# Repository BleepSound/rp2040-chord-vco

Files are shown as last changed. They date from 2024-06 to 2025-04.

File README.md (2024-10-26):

# RP2040 VCO (Clone, made by Hagiwo)

VCO clone, originally made by HAGIWO ([link](https://note.com/solder_state/n/n64b91a171218) in japanese)

RP2040 chord VCO clone in SMD.

5-polyphonic Chord VCO module.
There are 8 types of tones.
With a built-in quantizer and automatic harmonics function, if you input a suitable CV, it will play a nice chord progression.

**Switch indications:**

You'll notice numbers along the central 3 position switch. The table below explains each position's function. 

| Position | 1 | 2 | 3 |
|---|:---:|:---:|:---:|
| Function | arpeggio | chord with root | chord without root |

## Schematics

RP2040 VCO schematic

## BoM

[See bom](documentation/bom/RP2040-VCO_V1.2--iBoM.html)

## Build Informations

Full CMS build

:warning: When building this module, do it in this order (from smallest component to highest):

- Start by soldering all the CMS components in the order you want on both sides of the PCB.
- Then do all the through hole components
- To solder the headers, place them and place both PCBs in their final postion before fully soldering the pin headers/sockets.

For the next parts, always place them without soldering them on: 
- jacks, pots and switches that go throught the front panel

Once placed, put the front panel in place, then fasten all components to it. Once this is done, you can solder all the remaining components.

### V1.1
- you HAVE TO rotate SW1 180° for the built in LED to work.
- Issues on front panel (wrong label and missing info)

### V1.2
 - Fix issues on SW1
 - Update front panel look to include all informations

## Images

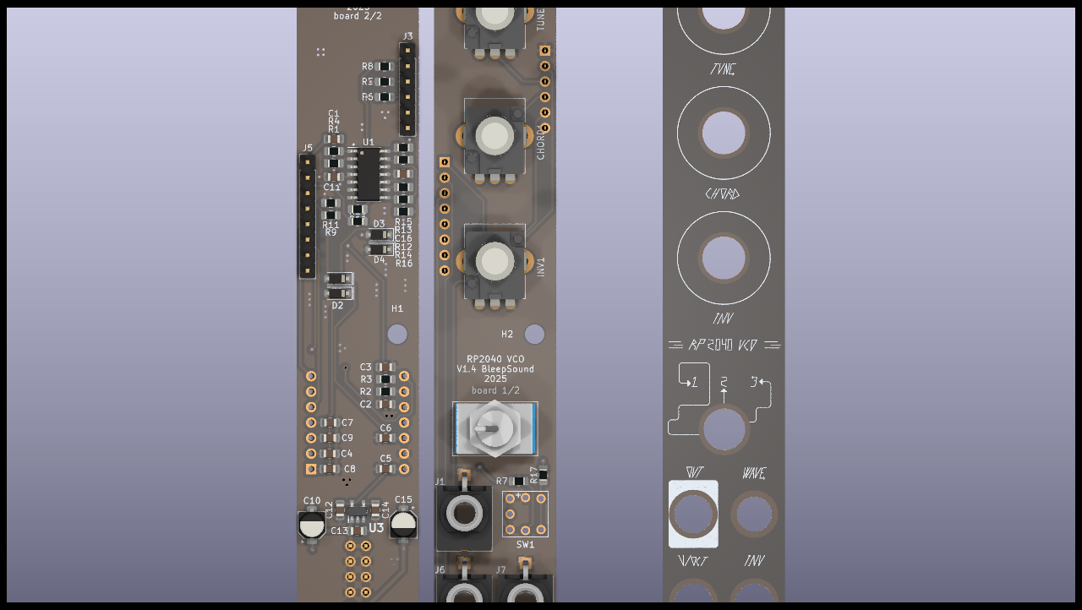
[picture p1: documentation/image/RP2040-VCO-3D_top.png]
3D (front)


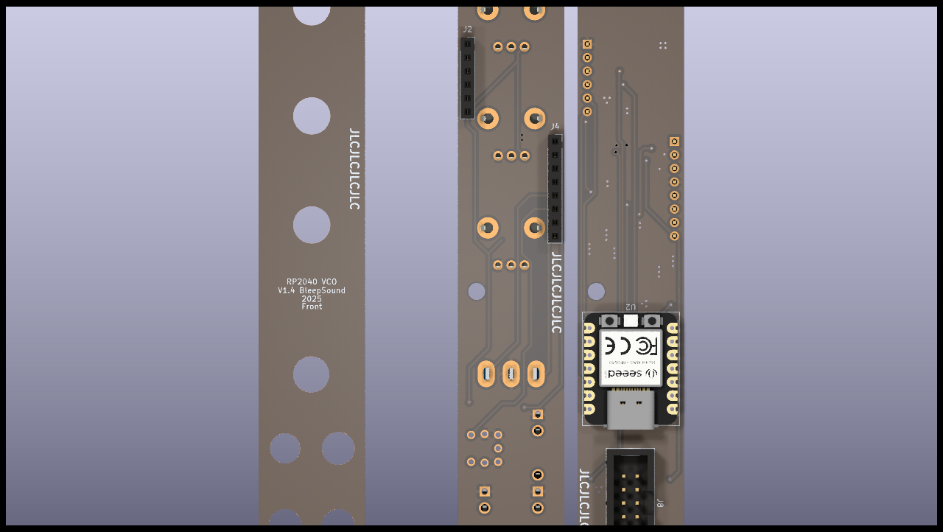
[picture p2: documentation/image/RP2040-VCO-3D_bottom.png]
3D (back)


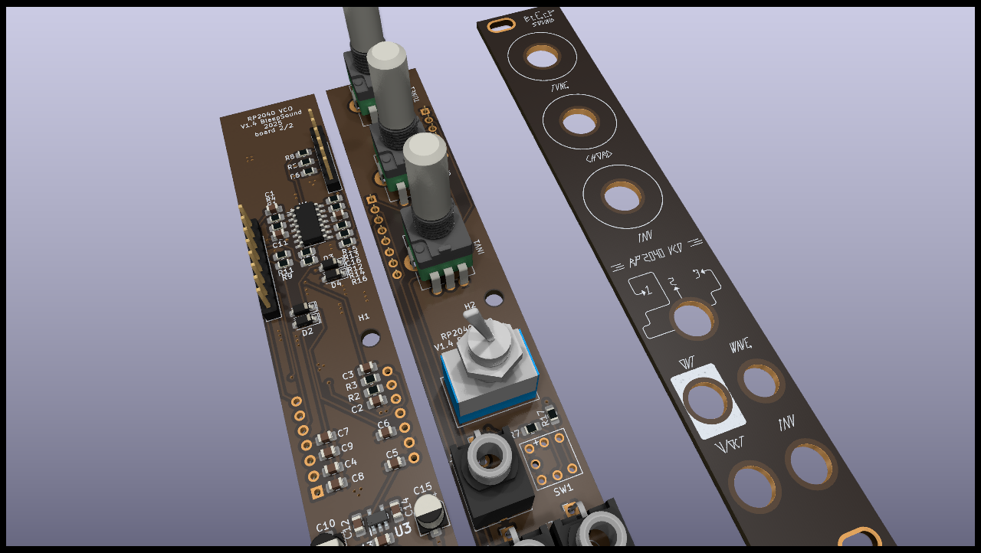
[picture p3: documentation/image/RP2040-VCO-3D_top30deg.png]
3D (iso)


## Software

You'll find the software for that module in the soft folder.

The microcontroler model is: **Seeed XIAO RP2040**

To flash it, use a usb-c cable to connect the RP2040 to your computer and use the arduino IDE (or your preferred IDE) to flash the microcontroler.

If you need any help, you can find a tutorial on how to flash a software via arduino onto a RP2040 [here](https://wiki.seeedstudio.com/XIAO-RP2040-with-Arduino/).

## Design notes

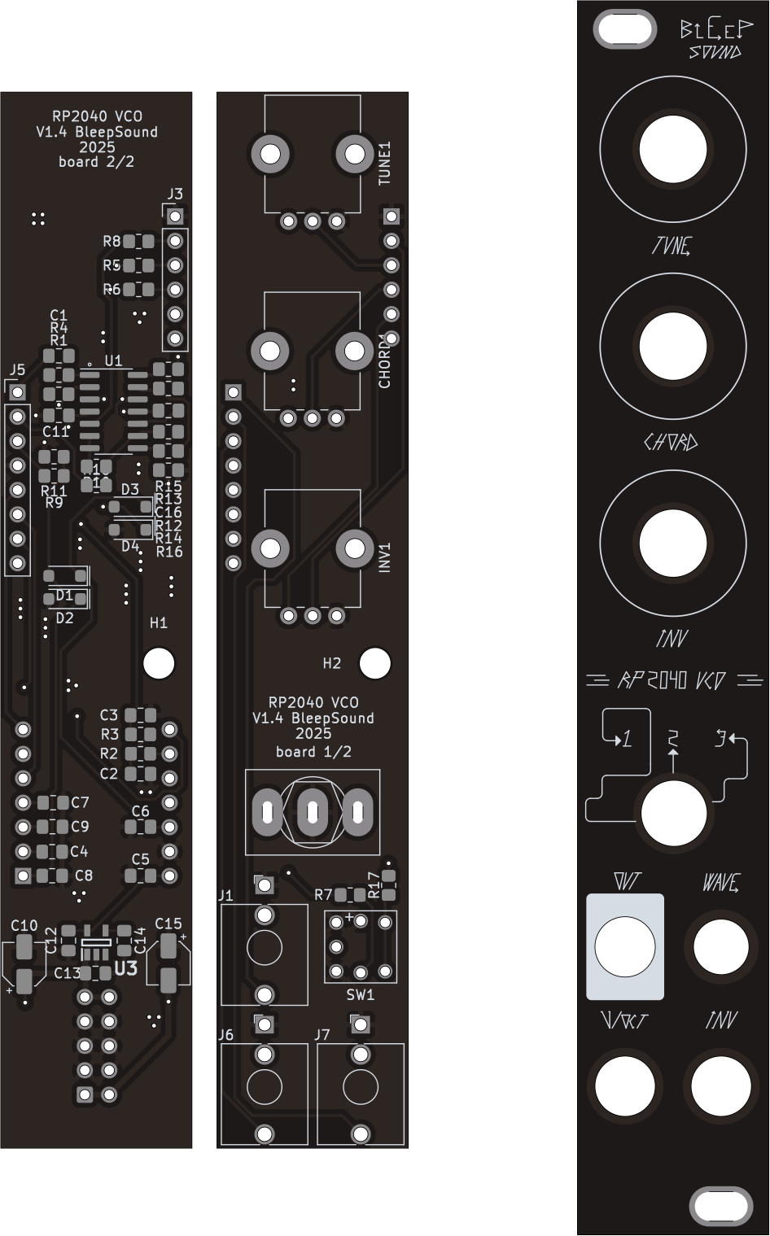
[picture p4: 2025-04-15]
documentation/image/RP2040-VCO-top.png

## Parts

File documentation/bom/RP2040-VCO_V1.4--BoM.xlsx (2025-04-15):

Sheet: BoM
RP2040-VCO_V1.4 Bill of Materials
Schematic: | RP2040-VCO | Component Groups: | 28
Variant: | default | Component Count: | 54 (39 SMD/ 14 THT)
Revision: | 1.4 | Fitted Components: | 54 (39 SMD/ 14 THT)
Date: | 2025-04-15 | Number of PCBs: | 1
KiCad Version: | 8.0.6-8.0.6-0~ubuntu22.04.1 | Total Components: | 54
Row | Description | References | Value | Quantity Per PCB | Manufacturer | Manufacturer ref | Links
1 | 0805 SMD cap 10% 25V | C14 | 100pF | 1 | Wurth Elektronik | 885012207054 | Mouser/RS/Digikey
2 | 0805 SMD cap 10% 25V | C1 C2 C3 C8 C9 | 10nF | 5 | Samsung Electro-Mechanics | CL21B103KAANNNC
3 | 0805 SMD cap 10% 25V | C4 C5 C7 C11 C16 | 100nF | 5 | Kemet | C0805C104M3RAC7210 | Mouser/RS/Digikey
4 | 0805 SMD cap 10% 25V | C13 | 1uF | 1 | Samsung Electro-Mechanics | CL21B105KAFNFNE | Mouser/RS/Digikey
5 | 0805 SMD cap 10% 25V | C12 | 2.2uF | 1 | Samsung Electro-Mechanics | CL21A225KAFNNNE | Mouser/RS/Digikey
6 | 0805 SMD cap 10% 25V | C10 C15 | 10uF | 2 | Kemet | EXV106M025S9BAA | Mouser/RS/Digikey
7 | 0805 SMD cap 10% 25V | C6 | 10uF | 1 | Samsung Electro-Mechanics | CL21A106KAYNNNE | Mouser/RS/Digikey
8 | Alpha/bourns vertical potentiometer | CHORD1 INV1 TUNE1 | 10k | 3 |  |  | https://www.thonk.co.uk/shop/alpha-9mm-pots/
9 | Schottky diode 30V 0.2A SOD-123 | D1 D2 D3 D4 | BAT43 (http://www.vishay.com/docs/85660/bat42.pdf) | 4 | Panjit | BAT43W_R1_00001 | Mouser/RS/Digikey
10 | 2.54mm pitch pin socket vertical 1x06pos | J2 | Conn_01x06_Female | 1
11 | 2.54mm pitch pin header vertical 1x06pos | J3 | Conn_01x06_Male | 1
12 | 2.54mm pitch pin socket vertical 1x08pos | J4 | Conn_01x08_Female | 1
13 | 2.54mm pitch pin header vertical 1x08pos | J5 | Conn_01x08_Male | 1
14 | Thonkiconn jack | J1 J6 J7 | Out | 3 |  |  | https://www.thonk.co.uk/shop/thonkiconn/
15 | Eurorack 10 pin shrouded power header IDC | J8 | Power Input | 1 |  |  | https://www.thonk.co.uk/shop/eurorack-diy-essentials/
16 | 0805 SMD resistor 5% | R4 R7 | 330R | 2 | YAGEO | RC0805FR-10330RL | Mouser/RS/Digikey
17 | 0805 SMD resistor 5% | R2 R3 R5 R6 | 1k | 4 | KOA Speer | RK73H2ATTE1001F | Mouser/RS/Digikey
18 | 0805 SMD resistor 5% | R1 | 6.8k | 1 | KOA Speer | RK73B2ATTDD682J | Mouser/RS/Digikey
19 | 0805 SMD resistor 5% | R8 R10 R12 R13 R14 R17 R18 | 10k | 7 | YAGEO | RC0805FR-1010KL | Mouser/RS/Digikey
20 | 0805 SMD resistor 5% | R15 | 22k | 1 | YAGEO | RC0805FR-1322KL | Mouser/RS/Digikey
21 | 0805 SMD resistor 5% | R16 | 33k | 1 | KOA Speer | RK73H2ATTD3302F | Mouser/RS/Digikey
22 | 0805 SMD resistor 5% | R9 | 220k | 1 | YAGEO | RC0805FR-13220KL | Mouser/RS/Digikey
23 | 0805 SMD resistor 5% | R11 | 330k | 1 | KOA Speer | RK73H2ATTD3303F | Mouser/RS/Digikey
24 | Low profile LED buttons (from Thonk) | SW1 | SW_MEC_LOW_PROF_LED (https://www.thonk.co.uk/wp-content/uploads/2021/12/LowProfileButton.pdf) | 1 | THONK | Low-Profile LED Buttons | https://www.thonk.co.uk/shop/low-profile-led-buttons/
25 | SPDT On-Off-On switch | SW2 | SW_SPDT (https://www.taydaelectronics.com/mini-toggle-switch-1m-series-spdt-on-off-on.html) | 1 |  | SPDT On-Off-On switch | https://www.taydaelectronics.com/mini-toggle-switch-1m-series-spdt-on-off-on-short-lever-pcb-pins.html
26 | 300mA 5.0V CMOS LDO | U3 | AP2210K-5.0TRG1 (https://componentsearchengine.com/Datasheets/1/AP2210K-5.0TRG1.pdf) | 1 | Diodes Inc. | AP2210K-5.0TRG1 | Mouser/RS/Digikey
27 | Seed Studio Xiao board with RP2040 microcontroler | U2 | Seed_XIAO_RP2040 (https://wiki.seeedstudio.com/XIAO-RP2040/) | 1 | Seeed Studio | Seeed Studio XIAO RP2040 | https://www.amazon.co.uk/Microcontroller-Dual-Core-MicroPython-CircuitPython-Interfaces/dp/B09XTCXJKW
28 | Quad SMD OpAmp | U1 | TL074 (http://www.ti.com/lit/ds/symlink/tl071.pdf) | 1 | Texas Instrument | TL074CDR | Mouser/RS/Digikey

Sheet: Colors
Columns colors
KiCad Fields (default)
Generated Fields
User Fields
Empty Fields

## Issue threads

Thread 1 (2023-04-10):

Where to find the push-button?

atoav, 2023-04-10:
I have a hard time sourcing the right switch for `MEC Low Profile single pole normally-open illuminated tactile switch`. Is there an actual manufacturer part number (MPN) I could look for?

comejar, 2023-05-13:
CANNOT CONFIRM THIS YET

But googling the part number in BOM shows a datasheet from thonk and looking on their site this is the button that matches that datasheet and part number

https://www.thonk.co.uk/shop/low-profile-led-buttons/

again i cannot confirm this is right for anyone who sees this, will update when i build this module to let you know for sure

atoav, 2023-05-20:
I have the high profile version of that switch and can verify that it works. The LED on that switch is bicolor, which means the way you put it in decides the color. Because the supply voltage for that switch is negative, the color of the leg pointing *down* will be the color in which it glows.

Because the LED serves no purpose other than lighting the button itself, there is another, more common button that should work (pictured right):

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

I confirmed with the continuity check of the multimeter that these two are switching the same pins through, so you don't get the LED, but if you don't need that you can also take that switch.

arthursaunier, 2023-06-10:
Can confirm it's the one from Thonk originally @comejar. It's the only place I found those types of buttons. Any other button like the one proposed by @atoav should work !

Closed 2023-09-01.

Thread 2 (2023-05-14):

What is the status of this module? tested?

comejar, 2023-05-14:
Was wondering you this has been built and tested before or if it is just in untested state still

Unlike your other github this one doesnt have the markings for where a module currently is at

atoav, 2023-05-20:
I just built one and it produces sounds and all he knobs/switches/buttons perform their functions. What I did not test yet, is the CV inputs, but given the simple nature of the circuit it would surprise me if it didn't work.

comejar, 2023-05-20:
> I just built one and it produces sounds and all he knobs/switches/buttons perform their functions. What I did not test yet, is the CV inputs, but given the simple nature of the circuit it would surprise me if it didn't work.

Great to hear thanks a lot for the response, hopefully the cv works too !

arthursaunier, 2023-06-10:
Hey guys, sorry was a bit out of it for the past few months.

Yes this module works and is tested !

I updated the documentation to show that on the website.

cheers

Closed 2023-09-01.

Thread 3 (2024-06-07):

Warbling noise

Pabcandy, 2024-06-07:
Hi, I built this today but get a strange warbling tone on all settings similar to excessive pwm or fm. On initial press of the button I get what I is how it should sound for about a second before it warbles. Tried re flashing the software so it might be a build error but I can’t see any problems with the hardware. Any ideas on where I might have gone wrong?
I can put a link to a video if that helps?
Thank you very much for putting this out there, it really is appreciated.
Phil

Pabcandy, 2024-06-08:
HI,
I reverted to v1.1 and the issue resolved - I thought it was a software issue as when the button is first pressed the sound is pure for about a second - so it must be the debounce.
Thanks

arthursaunier, 2024-06-12:
Hello Phil!
Sorry I was not very active this past few months on github.
I checked on my side and as you said it's a soft issue. I'm gonna update the repo right away.
Cheers!

Closed 2024-06-12.

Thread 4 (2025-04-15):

Missing resister in Inversion CV input

dlakwi, 2025-04-15:
The Inversion (Inv) CV input has no resister on its input from the jack to U1C inverting input at pin 9.
The original HaGiWo schematic has a 10k resister there.

arthursaunier, 2025-04-15:
Hey Donald, You were right. I modified the board.
It's all fixed in version 1.4

Closed 2025-04-15.

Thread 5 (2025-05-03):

potentiometers are reversed

dlakwi, 2025-05-03:
The three potentiometers Tune, Chord, and Inv are reversed.
For Tune, the lowest frequency is full CW.
For Chord and Inv, it's not noticeable since the direction is arbitrary.

For Tune and Chord, the direction can be reversed in the sketch.
For Inv, the PCB needs changing since the Inv CV input is summed with the Inv potentiometer.

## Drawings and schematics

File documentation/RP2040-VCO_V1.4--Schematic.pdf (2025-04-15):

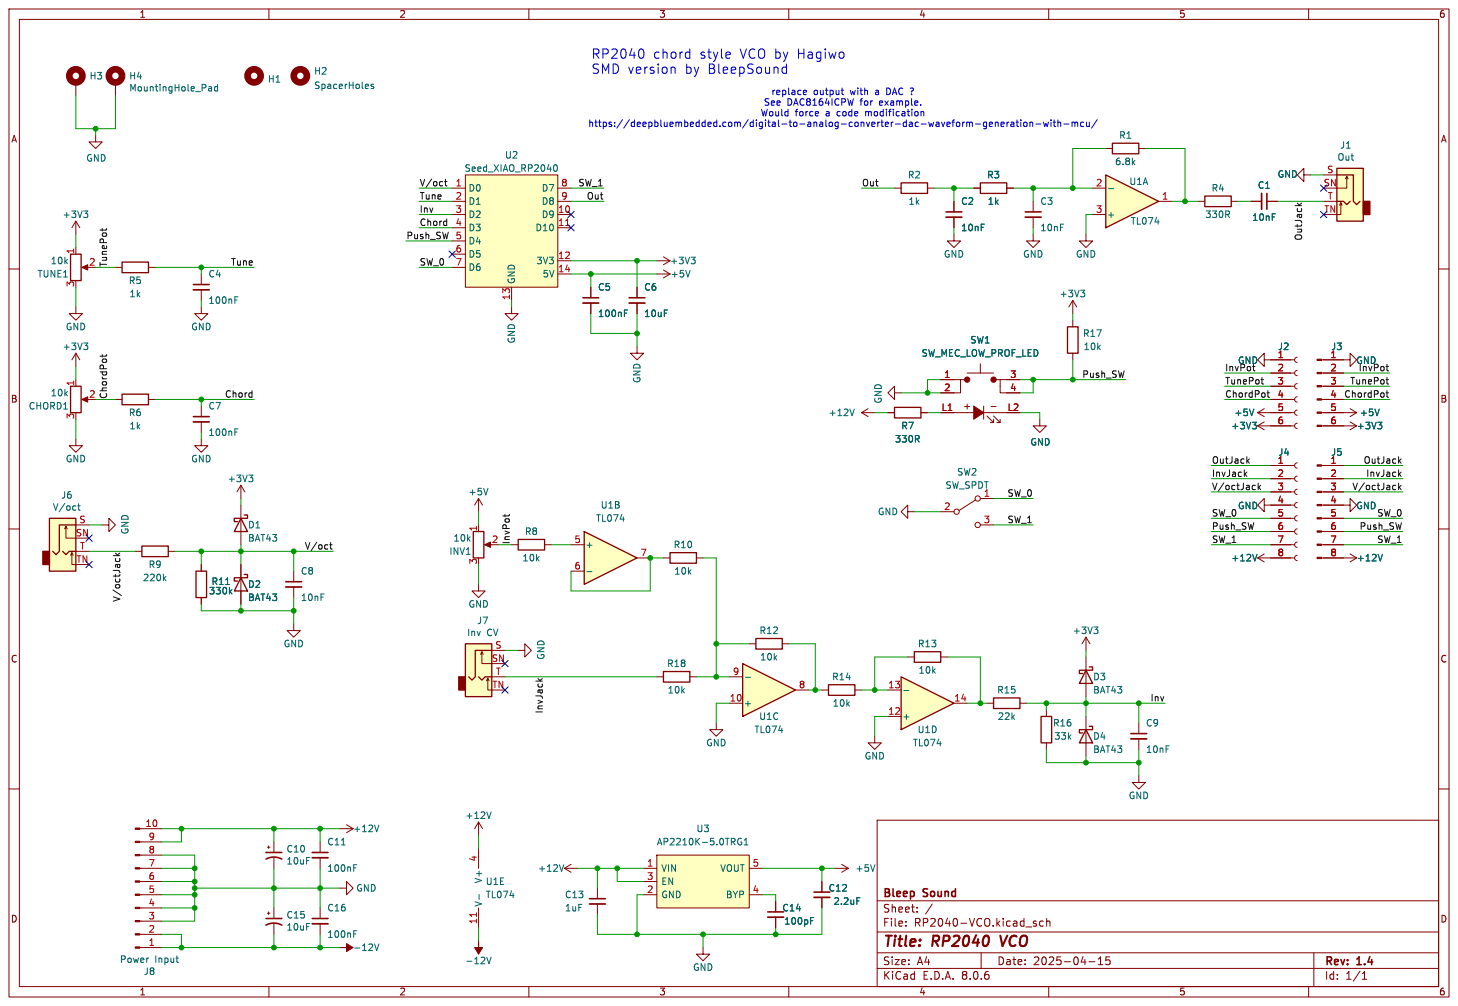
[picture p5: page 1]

SMD version by BleepSound

replace output with a DAC ? See DAC8164ICPW for example. Would force a code modification

https://deepbluembedded.com/digital-to-analog-converter-dac-waveform-generation-with-mcu/

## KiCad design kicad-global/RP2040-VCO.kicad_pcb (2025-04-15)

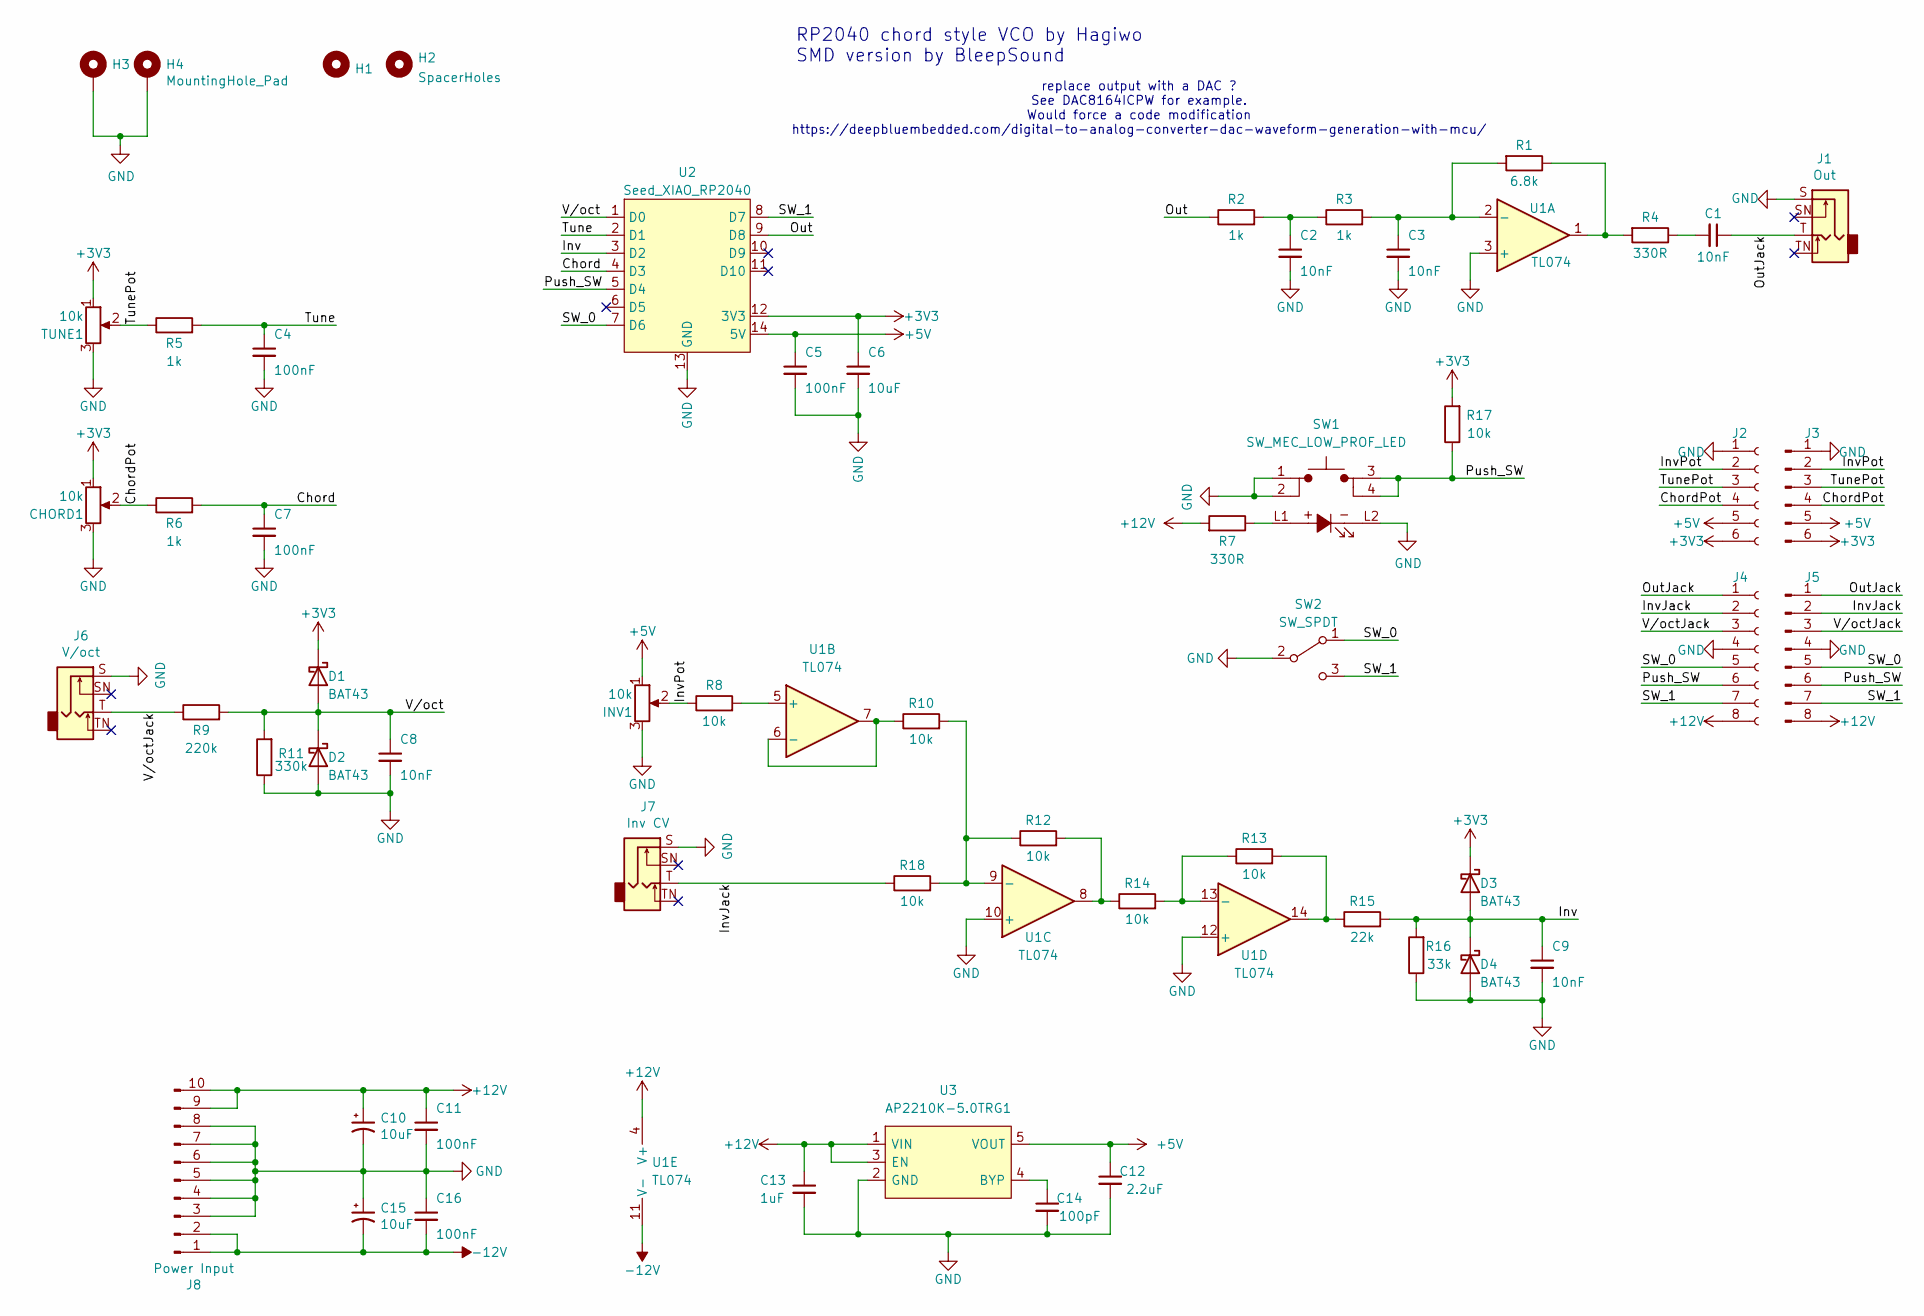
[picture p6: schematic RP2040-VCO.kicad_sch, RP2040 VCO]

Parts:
C1, C2, C3, C8, C9: 10nF; C_0805_2012Metric_Pad1.18x1.45mm_HandSolder
C4, C5, C7, C11, C16: 100nF; C_0805_2012Metric_Pad1.18x1.45mm_HandSolder
C6: 10uF; C_0805_2012Metric_Pad1.18x1.45mm_HandSolder
C10, C15: 10uF; CP_Elec_4x5.4
C12: 2.2uF; C_0805_2012Metric_Pad1.18x1.45mm_HandSolder
C13: 1uF; C_0805_2012Metric_Pad1.18x1.45mm_HandSolder
C14: 100pF; C_0805_2012Metric_Pad1.18x1.45mm_HandSolder
CHORD1: 10k; Pot-bourns-alpha
D1, D2, D3, D4: BAT43; D_SOD-123
H1, H2: SpacerHoles; MountingHole_3.2mm_M3
H3, H4: MountingHole_Pad; Doepfer Mounting hole
INV1: 10k; Pot-bourns-alpha
J1: Out; Thonkiconn
J2: Conn_01x06_Female; PinSocket_1x06_P2.54mm_Vertical
J3: Conn_01x06_Male; PinHeader_1x06_P2.54mm_Vertical
J4: Conn_01x08_Female; PinSocket_1x08_P2.54mm_Vertical
J5: Conn_01x08_Male; PinHeader_1x08_P2.54mm_Vertical
J6: V/oct; Thonkiconn
J7: Inv CV; Thonkiconn
J8: Power Input; IDC-Header_2x05_P2.54mm_Vertical
R1: 6.8k; R_0805_2012Metric_Pad1.20x1.40mm_HandSolder
R2, R3, R5, R6: 1k; R_0805_2012Metric_Pad1.20x1.40mm_HandSolder
R4, R7: 330R; R_0805_2012Metric_Pad1.20x1.40mm_HandSolder
R8, R10, R12, R13, R14, R17, R18: 10k; R_0805_2012Metric_Pad1.20x1.40mm_HandSolder
R9: 220k; R_0805_2012Metric_Pad1.20x1.40mm_HandSolder
R11: 330k; R_0805_2012Metric_Pad1.20x1.40mm_HandSolder
R15: 22k; R_0805_2012Metric_Pad1.20x1.40mm_HandSolder
R16: 33k; R_0805_2012Metric_Pad1.20x1.40mm_HandSolder
SW1: SW_MEC_LOW_PROF_LED; PB01-109TL
SW2: SW_SPDT; SW_Toggle_Blue_wSlots
TUNE1: 10k; Pot-bourns-alpha
U1: TL074; SOIC-14_3.9x8.7mm_P1.27mm
U2: Seed_XIAO_RP2040; Seed XIAO RP2040
U3: AP2210K-5.0TRG1; SOT95P282X130-5N

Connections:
+3V3: C6.1, CHORD1.1, D1.1 (K), D3.1 (K), J2.6, J3.6, R17.2, TUNE1.1, U2.12 (3V3)
+5V: C5.1, C12.1, INV1.1, J2.5, J3.5, U2.14 (5V), U3.5 (VOUT)
+12V: C10.1, C11.1, C13.1, J4.8, J5.8, J8.9, J8.10, R7.2, U1.4 (V+), U3.1 (VIN), U3.3 (EN)
-12V: C15.2, C16.2, J8.1, J8.2, U1.11 (V-)
/Chord: C7.1, R6.2, U2.4 (D3)
/ChordPot: CHORD1.2, J2.4, J3.4, R6.1
/Inv: C9.1, D3.2 (A), D4.1 (K), R15.2, R16.2, U2.3 (D2)
/InvJack: J4.2, J5.2, J7.T, R18.1
/InvPot: INV1.2, J2.2, J3.2, R8.1
/Out: R2.1, U2.9 (D8)
/OutJack: C1.1, J1.T, J4.1, J5.1
/Push_SW: J4.6, J5.6, R17.1, SW1.3, SW1.4, U2.5 (D4)
/SW_0: J4.5, J5.5, SW2.1 (A), U2.7 (D6)
/SW_1: J4.7, J5.7, SW2.3 (C), U2.8 (D7)
/Tune: C4.1, R5.2, U2.2 (D1)
/TunePot: J2.3, J3.3, R5.1, TUNE1.2
/V/oct: C8.1, D1.2 (A), D2.1 (K), R9.2, R11.2, U2.1 (D0)
/V/octJack: J4.3, J5.3, J6.T, R9.1
GND: C2.2, C3.2, C4.2, C5.2, C6.2, C7.2, C8.2, C9.2, C10.2, C11.2, C12.2, C13.2, C14.2, C15.1, C16.1, CHORD1.3, D2.2 (A), D4.2 (A), H3.1, H4.1, INV1.3, J1.S, J2.1, J3.1, J4.4, J5.4, J6.S, J7.S, J8.3, J8.4, J8.5, J8.6, J8.7, J8.8, R11.1, R16.1, SW1.1, SW1.2, SW1.L2, SW2.2 (B), TUNE1.3, U1.3 (+), U1.10 (+), U1.12 (+), U2.13 (GND), U3.2 (GND)
unnamed: C1.2, R4.1
unnamed: C2.1, R2.2, R3.1
unnamed: R1.1, R4.2, U1.1
unnamed: R7.1, SW1.L1
unnamed: R12.2, R14.1, U1.8
unnamed: R13.2, R15.1, U1.14
unnamed: C3.1, R1.2, R3.2, U1.2 (-)
unnamed: R8.2, U1.5 (+)
unnamed: R10.1, U1.6 (-), U1.7
unnamed: R10.2, R12.1, R18.2, U1.9 (-)
unnamed: R13.1, R14.2, U1.13 (-)
unnamed: C14.1, U3.4 (BYP)

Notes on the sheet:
replace output with a DAC ? See DAC8164ICPW for example. Would force a code modification https://deepbluembedded.com/digital-to-analog-converter-dac-waveform-generation-with-mcu/
RP2040 chord style VCO by Hagiwo SMD version by BleepSound

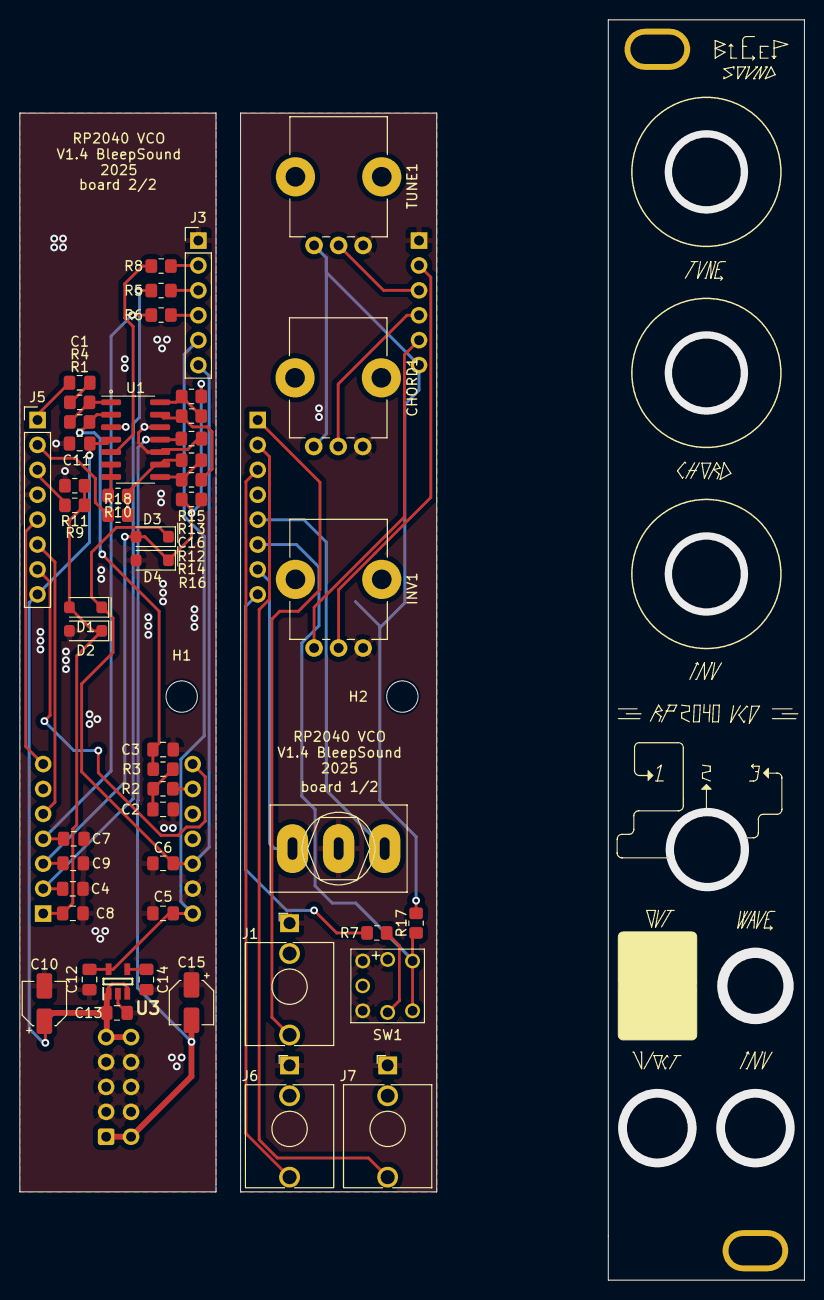
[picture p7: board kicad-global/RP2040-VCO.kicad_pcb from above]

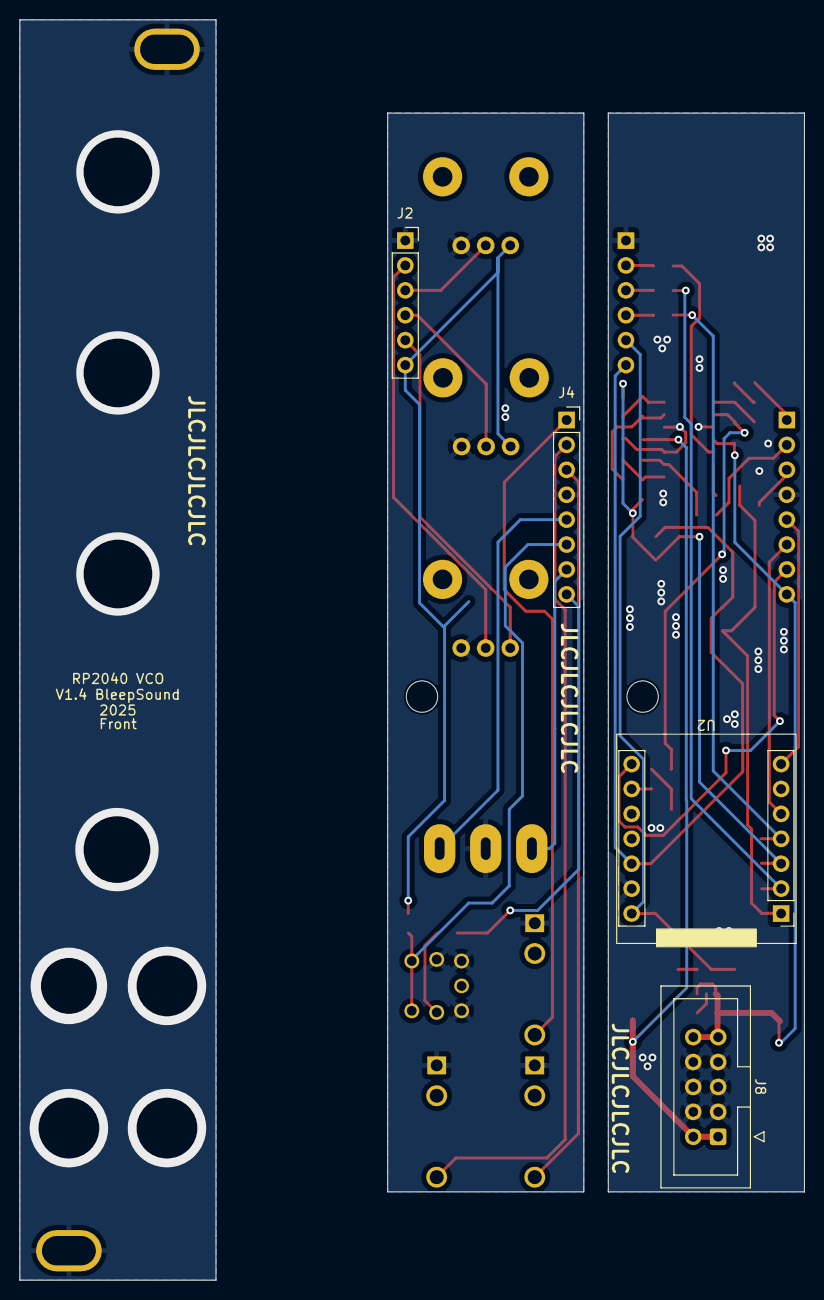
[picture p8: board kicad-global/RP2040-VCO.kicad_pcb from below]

Board: 2 copper layers, 80.0 x 128.5 mm, 58 parts (4 on the bottom side), 31 nets.

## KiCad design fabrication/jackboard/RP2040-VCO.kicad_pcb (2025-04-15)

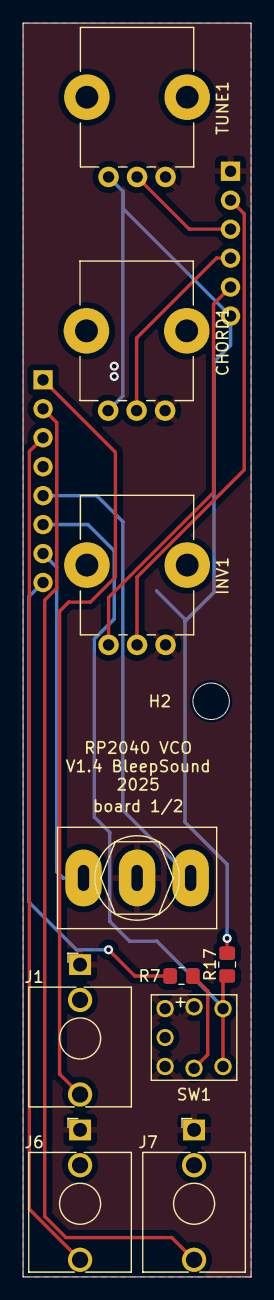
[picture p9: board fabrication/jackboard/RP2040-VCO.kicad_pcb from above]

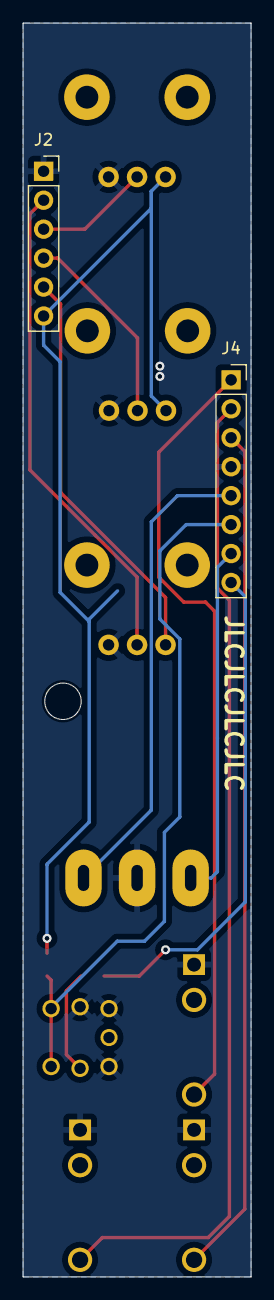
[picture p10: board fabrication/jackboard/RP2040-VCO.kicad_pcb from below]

Board: 2 copper layers, 20.0 x 110.0 mm, 13 parts (2 on the bottom side), 14 nets.

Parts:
CHORD1: 10k; Pot-bourns-alpha
H2: SpacerHoles; MountingHole_3.2mm_M3
INV1: 10k; Pot-bourns-alpha
J1: Out; Thonkiconn
J2: Conn_01x06_Female; PinSocket_1x06_P2.54mm_Vertical
J4: Conn_01x08_Female; PinSocket_1x08_P2.54mm_Vertical
J6: V/oct; Thonkiconn
J7: Inv CV; Thonkiconn
R7: 330R; R_0805_2012Metric_Pad1.20x1.40mm_HandSolder
R17: 10k; R_0805_2012Metric_Pad1.20x1.40mm_HandSolder
SW1: SW_MEC_LOW_PROF_LED; PB01-109TL
SW2: SW_SPDT; SW_Toggle_Blue_wSlots
TUNE1: 10k; Pot-bourns-alpha

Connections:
+3V3: CHORD1.1, J2.6, R17.2, TUNE1.1
+5V: INV1.1, J2.5
+12V: J4.8, R7.2
/ChordPot: CHORD1.2, J2.4
/InvJack: J4.2, J7.T
/InvPot: INV1.2, J2.2
/OutJack: J1.T, J4.1
/Push_SW: J4.6, R17.1, SW1.3, SW1.4
/SW_0: J4.5, SW2.1 (A)
/SW_1: J4.7, SW2.3 (C)
/TunePot: J2.3, TUNE1.2
/V/octJack: J4.3, J6.T
GND: CHORD1.3, INV1.3, J1.S, J2.1, J4.4, J6.S, J7.S, SW1.1, SW1.2, SW1.L2, SW2.2 (B), TUNE1.3
unnamed: R7.1, SW1.L1

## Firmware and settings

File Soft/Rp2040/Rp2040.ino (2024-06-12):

#include <hardware/pwm.h>

float osc_progress[6];//0~4=chord osc , 5=bass osc , 6=arpeggio osc
int osc_inverse[4];
float osc_scale_rate[5];//0~3=chord osc , 6=arpeggio osc
int slice_num = 0;
float osc_freq = 0;
int wavetable[256];//1024 resolution , 256 rate
float calb = 1.11;//calibration for reduce resistance error
int  adc, freq_pot;
int waveform = 0;
int f0 = 35;//base osc frequency

int j=0;
int select_mode=0;//0=chord without root , 1=chord with root,2=arpeggio
int inversion=0;//0-7
int old_invAD=0;//countermeasure of input ADC noise
int new_invAD=0;//countermeasure of input ADC noise
bool push_sw, old_push_sw;//push sw

int qnt[32];
int thr=0;//threshold number
const static int majqnt[32]={// major scale quantize value
0,	34,	68,	85,	119,	153,	205,	239,	273,	290,	324,	358,	409,	443,	477,	494,	529,	563,	614,	648,	682,	699,	733,	767,	818,	853,	887,	904,	938,	972,	1023
};

const static int majthr[32]={// major scale quantize threshold
 0, 17,	51,	85,	102,	136,	171,	222,	256,	290,	307,	341,	375,	426,	460,	494,	512,	546,	580,	631,	665,	699,	716,	750,	784,	835,	870,	904,	921,	955,	989,1024
};

const static int minqnt[32]={// minor scale quantize value
0,	34,	51,	85,	119,	136,	205,	239,	256,	290,	324,	341,	409,	443,	460,	494,	529,	546,	614,	648,	665,	699,	733,	750,	818,	853,	870,	904,	938,	955,	1023
};

const static int minthr[32]={// minor scale quantize threshold
 17,	43,	68,	102,	128,	171,	222,	248,	273,	307,	333,	375,	426,	452,	477,	512,	538,	580,	631,	657,	682,	716,	742,	784,	836,	862,	887,	921,	947,	989,	1024
};

//------------chord------------
float freq_rate[61]={
1,	1.059,	1.122,	1.189,	1.26,	1.335,	1.414,	1.498,	1.587,	1.682,	1.782,	1.888,	2,	2.059,	2.122,	2.189,	2.26,	2.335,	2.414,	2.498,	2.587,	2.682,	2.782,	2.888,	3,	3.059,	3.122,	3.189,	3.26,	3.335,	3.414,	3.498,	3.587,	3.682,	3.782,	3.888,	4,	4.059,	4.122,	4.189,	4.26,	4.335,	4.414,	4.498,	4.587,	4.682,	4.782,	4.888,	5,	5.059,	5.122,	5.189,	5.26,	5.335,	5.414,	5.498,	5.587,	5.682,	5.782,	5.888,	6
};

int chord_mode=2;//0=maj 3chord,1=min 3chord,2=tension maj 4chord,3=maj 4chord,4=min 4chord,5=tension min 4chord

int chord_3[3][3]={
{0,4,7},//maj
{0,3,7},//min
{0,3,6}//dim
};

int chord_4[6][4]={
  {0,4,7,11},//maj+M7
  {0,2,4,7},//maj+add9
  {0,4,7,10},//maj+7
  {0,3,7,10},//min+7
  {0,4,7,9},//maj+6
  {0,3,6,10}//dim+7
};

int select_chord3[3][6]={//6 is mode kinds
  {0,1,1,0,0,0},//maj -> I,IIm,IIIm,IV,V,VIm
  {0,1,1,0,0,1},//maj -> I,IIm,IIIm,IV,V,VI
  {1,2,0,1,1,0}//min -> Im,IIdim,III,IVm,Vm,VI
};

int select_chord4[3][6]={//6 is mode kinds
  {1,3,3,0,4,1},//maj -> Iadd9,IIm7,IIIm7,IVM7,V6,VIadd9
  {0,3,3,0,2,3},//maj -> IM7,IIm7,IIIm7,IVM7,V7,VIm7
  {3,5,0,3,3,0}//min -> Im7,IIdim7,IIIM7,IVm7,Vm7,VIM7
};

int select_table=0;

//-----------V/oct-----------
const static float voctpow[1230] = {//Covers 6(=1230) octaves. If it is 1230 or more, the operation becomes unstable.
  0,  0.004882, 0.009765, 0.014648, 0.019531, 0.024414, 0.029296, 0.034179, 0.039062, 0.043945, 0.048828, 0.05371,  0.058593, 0.063476, 0.068359, 0.073242, 0.078125, 0.083007, 0.08789,  0.092773, 0.097656, 0.102539, 0.107421, 0.112304, 0.117187, 0.12207,  0.126953, 0.131835, 0.136718, 0.141601, 0.146484, 0.151367, 0.15625,  0.161132, 0.166015, 0.170898, 0.175781, 0.180664, 0.185546, 0.190429, 0.195312, 0.200195, 0.205078, 0.20996,  0.214843, 0.219726, 0.224609, 0.229492, 0.234375, 0.239257, 0.24414,  0.249023, 0.253906, 0.258789, 0.263671, 0.268554, 0.273437, 0.27832,  0.283203, 0.288085, 0.292968, 0.297851, 0.302734, 0.307617, 0.3125, 0.317382, 0.322265, 0.327148, 0.332031, 0.336914, 0.341796, 0.346679, 0.351562, 0.356445, 0.361328, 0.36621,  0.371093, 0.375976, 0.380859, 0.385742, 0.390625, 0.395507, 0.40039,  0.405273, 0.410156, 0.415039, 0.419921, 0.424804, 0.429687, 0.43457,  0.439453, 0.444335, 0.449218, 0.454101, 0.458984, 0.463867, 0.46875,  0.473632, 0.478515, 0.483398, 0.488281, 0.493164, 0.498046, 0.502929, 0.507812, 0.512695, 0.517578, 0.52246,  0.527343, 0.532226, 0.537109, 0.541992, 0.546875, 0.551757, 0.55664,  0.561523, 0.566406, 0.571289, 0.576171, 0.581054, 0.585937, 0.59082,  0.595703, 0.600585, 0.605468, 0.610351, 0.615234, 0.620117, 0.625,  0.629882, 0.634765, 0.639648, 0.644531, 0.649414, 0.654296, 0.659179, 0.664062, 0.668945, 0.673828, 0.67871,  0.683593, 0.688476, 0.693359, 0.698242, 0.703125, 0.708007, 0.71289,  0.717773, 0.722656, 0.727539, 0.732421, 0.737304, 0.742187, 0.74707,  0.751953, 0.756835, 0.761718, 0.766601, 0.771484, 0.776367, 0.78125,  0.786132, 0.791015, 0.795898, 0.800781, 0.805664, 0.810546, 0.815429, 0.820312, 0.825195, 0.830078, 0.83496,  0.839843, 0.844726, 0.849609, 0.854492, 0.859375, 0.864257, 0.86914,  0.874023, 0.878906, 0.883789, 0.888671, 0.893554, 0.898437, 0.90332,  0.908203, 0.913085, 0.917968, 0.922851, 0.927734, 0.932617, 0.9375, 0.942382, 0.947265, 0.952148, 0.957031, 0.961914, 0.966796, 0.971679, 0.976562, 0.981445, 0.986328, 0.99121,  0.996093, 1.000976, 1.005859, 1.010742, 1.015625, 1.020507, 1.02539,  1.030273, 1.035156, 1.040039, 1.044921, 1.049804, 1.054687, 1.05957,  1.064453, 1.069335, 1.074218, 1.079101, 1.083984, 1.088867, 1.09375,  1.098632, 1.103515, 1.108398, 1.113281, 1.118164, 1.123046, 1.127929, 1.132812, 1.137695, 1.142578, 1.14746,  1.152343, 1.157226, 1.162109, 1.166992, 1.171875, 1.176757, 1.18164,  1.186523, 1.191406, 1.196289, 1.201171, 1.206054, 1.210937, 1.21582,  1.220703, 1.225585, 1.230468, 1.235351, 1.240234, 1.245117, 1.25, 1.254882, 1.259765, 1.264648, 1.269531, 1.274414, 1.279296, 1.284179, 1.289062, 1.293945, 1.298828, 1.30371,  1.308593, 1.313476, 1.318359, 1.323242, 1.328125, 1.333007, 1.33789,  1.342773, 1.347656, 1.352539, 1.357421, 1.362304, 1.367187, 1.37207,  1.376953, 1.381835, 1.386718, 1.391601, 1.396484, 1.401367, 1.40625,  1.411132, 1.416015, 1.420898, 1.425781, 1.430664, 1.435546, 1.440429, 1.445312, 1.450195, 1.455078, 1.45996,  1.464843, 1.469726, 1.474609, 1.479492, 1.484375, 1.489257, 1.49414,  1.499023, 1.503906, 1.508789, 1.513671, 1.518554, 1.523437, 1.52832,  1.533203, 1.538085, 1.542968, 1.547851, 1.552734, 1.557617, 1.5625, 1.567382, 1.572265, 1.577148, 1.582031, 1.586914, 1.591796, 1.596679, 1.601562, 1.606445, 1.611328, 1.61621,  1.621093, 1.625976, 1.630859, 1.635742, 1.640625, 1.645507, 1.65039,  1.655273, 1.660156, 1.665039, 1.669921, 1.674804, 1.679687, 1.68457,  1.689453, 1.694335, 1.699218, 1.704101, 1.708984, 1.713867, 1.71875,  1.723632, 1.728515, 1.733398, 1.738281, 1.743164, 1.748046, 1.752929, 1.757812, 1.762695, 1.767578, 1.77246,  1.777343, 1.782226, 1.787109, 1.791992, 1.796875, 1.801757, 1.80664,  1.811523, 1.816406, 1.821289, 1.826171, 1.831054, 1.835937, 1.84082,  1.845703, 1.850585, 1.855468, 1.860351, 1.865234, 1.870117, 1.875,  1.879882, 1.884765, 1.889648, 1.894531, 1.899414, 1.904296, 1.909179, 1.914062, 1.918945, 1.923828, 1.92871,  1.933593, 1.938476, 1.943359, 1.948242, 1.953125, 1.958007, 1.96289,  1.967773, 1.972656, 1.977539, 1.982421, 1.987304, 1.992187, 1.99707,  2.001953, 2.006835, 2.011718, 2.016601, 2.021484, 2.026367, 2.03125,  2.036132, 2.041015, 2.045898, 2.050781, 2.055664, 2.060546, 2.065429, 2.070312, 2.075195, 2.080078, 2.08496,  2.089843, 2.094726, 2.099609, 2.104492, 2.109375, 2.114257, 2.11914,  2.124023, 2.128906, 2.133789, 2.138671, 2.143554, 2.148437, 2.15332,  2.158203, 2.163085, 2.167968, 2.172851, 2.177734, 2.182617, 2.1875, 2.192382, 2.197265, 2.202148, 2.207031, 2.211914, 2.216796, 2.221679, 2.226562, 2.231445, 2.236328, 2.24121,  2.246093, 2.250976, 2.255859, 2.260742, 2.265625, 2.270507, 2.27539,  2.280273, 2.285156, 2.290039, 2.294921, 2.299804, 2.304687, 2.30957,  2.314453, 2.319335, 2.324218, 2.329101, 2.333984, 2.338867, 2.34375,  2.348632, 2.353515, 2.358398, 2.363281, 2.368164, 2.373046, 2.377929, 2.382812, 2.387695, 2.392578, 2.39746,  2.402343, 2.407226, 2.412109, 2.416992, 2.421875, 2.426757, 2.43164,  2.436523, 2.441406, 2.446289, 2.451171, 2.456054, 2.460937, 2.46582,  2.470703, 2.475585, 2.480468, 2.485351, 2.490234, 2.495117, 2.5,  2.504882, 2.509765, 2.514648, 2.519531, 2.524414, 2.529296, 2.534179, 2.539062, 2.543945, 2.548828, 2.55371,  2.558593, 2.563476, 2.568359, 2.573242, 2.578125, 2.583007, 2.58789,  2.592773, 2.597656, 2.602539, 2.607421, 2.612304, 2.617187, 2.62207,  2.626953, 2.631835, 2.636718, 2.641601, 2.646484, 2.651367, 2.65625,  2.661132, 2.666015, 2.670898, 2.675781, 2.680664, 2.685546, 2.690429, 2.695312, 2.700195, 2.705078, 2.70996,  2.714843, 2.719726, 2.724609, 2.729492, 2.734375, 2.739257, 2.74414,  2.749023, 2.753906, 2.758789, 2.763671, 2.768554, 2.773437, 2.77832,  2.783203, 2.788085, 2.792968, 2.797851, 2.802734, 2.807617, 2.8125, 2.817382, 2.822265, 2.827148, 2.832031, 2.836914, 2.841796, 2.846679, 2.851562, 2.856445, 2.861328, 2.86621,  2.871093, 2.875976, 2.880859, 2.885742, 2.890625, 2.895507, 2.90039,  2.905273, 2.910156, 2.915039, 2.919921, 2.924804, 2.929687, 2.93457,  2.939453, 2.944335, 2.949218, 2.954101, 2.958984, 2.963867, 2.96875,  2.973632, 2.978515, 2.983398, 2.988281, 2.993164, 2.998046, 3.002929, 3.007812, 3.012695, 3.017578, 3.02246,  3.027343, 3.032226, 3.037109, 3.041992, 3.046875, 3.051757, 3.05664,  3.061523, 3.066406, 3.071289, 3.076171, 3.081054, 3.085937, 3.09082,  3.095703, 3.100585, 3.105468, 3.110351, 3.115234, 3.120117, 3.125,  3.129882, 3.134765, 3.139648, 3.144531, 3.149414, 3.154296, 3.159179, 3.164062, 3.168945, 3.173828, 3.17871,  3.183593, 3.188476, 3.193359, 3.198242, 3.203125, 3.208007, 3.21289,  3.217773, 3.222656, 3.227539, 3.232421, 3.237304, 3.242187, 3.24707,  3.251953, 3.256835, 3.261718, 3.266601, 3.271484, 3.276367, 3.28125,  3.286132, 3.291015, 3.295898, 3.300781, 3.305664, 3.310546, 3.315429, 3.320312, 3.325195, 3.330078, 3.33496,  3.339843, 3.344726, 3.349609, 3.354492, 3.359375, 3.364257, 3.36914,  3.374023, 3.378906, 3.383789, 3.388671, 3.393554, 3.398437, 3.40332,  3.408203, 3.413085, 3.417968, 3.422851, 3.427734, 3.432617, 3.4375, 3.442382, 3.447265, 3.452148, 3.457031, 3.461914, 3.466796, 3.471679, 3.476562, 3.481445, 3.486328, 3.49121,  3.496093, 3.500976, 3.505859, 3.510742, 3.515625, 3.520507, 3.52539,  3.530273, 3.535156, 3.540039, 3.544921, 3.549804, 3.554687, 3.55957,  3.564453, 3.569335, 3.574218, 3.579101, 3.583984, 3.588867, 3.59375,  3.598632, 3.603515, 3.608398, 3.613281, 3.618164, 3.623046, 3.627929, 3.632812, 3.637695, 3.642578, 3.64746,  3.652343, 3.657226, 3.662109, 3.666992, 3.671875, 3.676757, 3.68164,  3.686523, 3.691406, 3.696289, 3.701171, 3.706054, 3.710937, 3.71582,  3.720703, 3.725585, 3.730468, 3.735351, 3.740234, 3.745117, 3.75, 3.754882, 3.759765, 3.764648, 3.769531, 3.774414, 3.779296, 3.784179, 3.789062, 3.793945, 3.798828, 3.80371,  3.808593, 3.813476, 3.818359, 3.823242, 3.828125, 3.833007, 3.83789,  3.842773, 3.847656, 3.852539, 3.857421, 3.862304, 3.867187, 3.87207,  3.876953, 3.881835, 3.886718, 3.891601, 3.896484, 3.901367, 3.90625,  3.911132, 3.916015, 3.920898, 3.925781, 3.930664, 3.935546, 3.940429, 3.945312, 3.950195, 3.955078, 3.95996,  3.964843, 3.969726, 3.974609, 3.979492, 3.984375, 3.989257, 3.99414,  3.999023, 4.003906, 4.008789, 4.013671, 4.018554, 4.023437, 4.02832,  4.033203, 4.038085, 4.042968, 4.047851, 4.052734, 4.057617, 4.0625, 4.067382, 4.072265, 4.077148, 4.082031, 4.086914, 4.091796, 4.096679, 4.101562, 4.106445, 4.111328, 4.11621,  4.121093, 4.125976, 4.130859, 4.135742, 4.140625, 4.145507, 4.15039,  4.155273, 4.160156, 4.165039, 4.169921, 4.174804, 4.179687, 4.18457,  4.189453, 4.194335, 4.199218, 4.204101, 4.208984, 4.213867, 4.21875,  4.223632, 4.228515, 4.233398, 4.238281, 4.243164, 4.248046, 4.252929, 4.257812, 4.262695, 4.267578, 4.27246,  4.277343, 4.282226, 4.287109, 4.291992, 4.296875, 4.301757, 4.30664,  4.311523, 4.316406, 4.321289, 4.326171, 4.331054, 4.335937, 4.34082,  4.345703, 4.350585, 4.355468, 4.360351, 4.365234, 4.370117, 4.375,  4.379882, 4.384765, 4.389648, 4.394531, 4.399414, 4.404296, 4.409179, 4.414062, 4.418945, 4.423828, 4.42871,  4.433593, 4.438476, 4.443359, 4.448242, 4.453125, 4.458007, 4.46289,  4.467773, 4.472656, 4.477539, 4.482421, 4.487304, 4.492187, 4.49707,  4.501953, 4.506835, 4.511718, 4.516601, 4.521484, 4.526367, 4.53125,  4.536132, 4.541015, 4.545898, 4.550781, 4.555664, 4.560546, 4.565429, 4.570312, 4.575195, 4.580078, 4.58496,  4.589843, 4.594726, 4.599609, 4.604492, 4.609375, 4.614257, 4.61914,  4.624023, 4.628906, 4.633789, 4.638671, 4.643554, 4.648437, 4.65332,  4.658203, 4.663085, 4.667968, 4.672851, 4.677734, 4.682617, 4.6875, 4.692382, 4.697265, 4.702148, 4.707031, 4.711914, 4.716796, 4.721679, 4.726562, 4.731445, 4.736328, 4.74121,  4.746093, 4.750976, 4.755859, 4.760742, 4.765625, 4.770507, 4.77539,  4.780273, 4.785156, 4.790039, 4.794921, 4.799804, 4.804687, 4.80957,  4.814453, 4.819335, 4.824218, 4.829101, 4.833984, 4.838867, 4.84375,  4.848632, 4.853515, 4.858398, 4.863281, 4.868164, 4.873046, 4.877929, 4.882812, 4.887695, 4.892578, 4.89746,  4.902343, 4.907226, 4.912109, 4.916992, 4.921875, 4.926757, 4.93164,  4.936523, 4.941406, 4.946289, 4.951171, 4.956054, 4.960937, 4.96582,  4.970703, 4.975585, 4.980468, 4.985351, 4.990234, 4.995117, 5,  5.004882, 5.009765, 5.014648, 5.019531, 5.024414, 5.029296, 5.034179, 5.039062, 5.043945, 5.048828, 5.05371,  5.058593, 5.063476, 5.068359, 5.073242, 5.078125, 5.083007, 5.08789,  5.092773, 5.097656, 5.102539, 5.107421, 5.112304, 5.117187, 5.12207,  5.126953, 5.131835, 5.136718, 5.141601, 5.146484, 5.151367, 5.15625,  5.161132, 5.166015, 5.170898, 5.175781, 5.180664, 5.185546, 5.190429, 5.195312, 5.200195, 5.205078, 5.20996,  5.214843, 5.219726, 5.224609, 5.229492, 5.234375, 5.239257, 5.24414,  5.249023, 5.253906, 5.258789, 5.263671, 5.268554, 5.273437, 5.27832,  5.283203, 5.288085, 5.292968, 5.297851, 5.302734, 5.307617, 5.3125, 5.317382, 5.322265, 5.327148, 5.332031, 5.336914, 5.341796, 5.346679, 5.351562, 5.356445, 5.361328, 5.36621,  5.371093, 5.375976, 5.380859, 5.385742, 5.390625, 5.395507, 5.40039,  5.405273, 5.410156, 5.415039, 5.419921, 5.424804, 5.429687, 5.43457,  5.439453, 5.444335, 5.449218, 5.454101, 5.458984, 5.463867, 5.46875,  5.473632, 5.478515, 5.483398, 5.488281, 5.493164, 5.498046, 5.502929, 5.507812, 5.512695, 5.517578, 5.52246,  5.527343, 5.532226, 5.537109, 5.541992, 5.546875, 5.551757, 5.55664,  5.561523, 5.566406, 5.571289, 5.576171, 5.581054, 5.585937, 5.59082,  5.595703, 5.600585, 5.605468, 5.610351, 5.615234, 5.620117, 5.625,  5.629882, 5.634765, 5.639648, 5.644531, 5.649414, 5.654296, 5.659179, 5.664062, 5.668945, 5.673828, 5.67871,  5.683593, 5.688476, 5.693359, 5.698242, 5.703125, 5.708007, 5.71289,  5.717773, 5.722656, 5.727539, 5.732421, 5.737304, 5.742187, 5.74707,  5.751953, 5.756835, 5.761718, 5.766601, 5.771484, 5.776367, 5.78125,  5.786132, 5.791015, 5.795898, 5.800781, 5.805664, 5.810546, 5.815429, 5.820312, 5.825195,
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
void loop()
{
  old_push_sw = push_sw;
  //  -------------------frequeny calculation-------------------------------
  adc = analogRead(26) * calb;//Correct resistance errors
  qnt_set();
  freq_pot = map(analogRead(27), 0, 1023, 0, 127);

  osc_freq = freq_table[qnt[thr] + freq_pot]; // V/oct apply
  osc_freq = 256 * osc_freq / 122070 * 8;//7 is base octave

  Serial.print(analogRead(26));//for development
  Serial.print(",");//for development
  Serial.print(adc);//for development
  Serial.println("");//for development

  //  -------------------chord mode select-------------------------------
  chord_mode = analogRead(29)/171;//171=1023/6 , 6 is amount of chord mode

  //---------------------inversion---------------------
  old_invAD=new_invAD;//countermeasure of noise
  new_invAD=analogRead(28);
  if(abs(old_invAD-new_invAD)<4){//countermeasure of noise
    new_invAD=old_invAD;
  }
  inversion=new_invAD/125;

  if(chord_mode==2 ||chord_mode==3 ||chord_mode==4){//3 chord
  switch(inversion){
    case 0:
      osc_inverse[0]=1;
      osc_inverse[1]=1;
      osc_inverse[2]=1;
      osc_scale_rate[4]=osc_scale_rate[0];
      break;
    
     case 1:
      osc_inverse[0]=2;
      osc_inverse[1]=1;
      osc_inverse[2]=1;
      osc_scale_rate[4]=osc_scale_rate[1];
      break;

    case 2:
      osc_inverse[0]=2;
      osc_inverse[1]=2;
      osc_inverse[2]=1;
      osc_scale_rate[4]=osc_scale_rate[2];  
      break;

    case 3:
      osc_inverse[0]=2;
      osc_inverse[1]=2;
      osc_inverse[2]=2;
      osc_scale_rate[4]=osc_scale_rate[0];
      break;

    case 4:
      osc_inverse[0]=4;
      osc_inverse[1]=2;
      osc_inverse[2]=2;
      osc_scale_rate[4]=osc_scale_rate[1];
      break;

    case 5:
      osc_inverse[0]=4;
      osc_inverse[1]=4;
      osc_inverse[2]=2;
      osc_scale_rate[4]=osc_scale_rate[2];
      break;

    case 6:
      osc_inverse[0]=4;
      osc_inverse[1]=4;
      osc_inverse[2]=4;
      osc_scale_rate[4]=osc_scale_rate[0];
      break;

    case 7:
      osc_inverse[0]=8;
      osc_inverse[1]=4;
      osc_inverse[2]=4;
      osc_scale_rate[4]=osc_scale_rate[1];
      break; 
  }
  }
    if(chord_mode==0 ||chord_mode==1||chord_mode==5){//4 chord
  switch(inversion){
    case 0:
      osc_inverse[0]=1;
      osc_inverse[1]=1;
      osc_inverse[2]=1;
      osc_inverse[3]=1;
      osc_scale_rate[4]=osc_scale_rate[0];
      break;
    
     case 1:
      osc_inverse[0]=2;
      osc_inverse[1]=1;
      osc_inverse[2]=1;
      osc_inverse[3]=1;
      osc_scale_rate[4]=osc_scale_rate[1];
      break;

    case 2:
      osc_inverse[0]=2;
      osc_inverse[1]=2;
      osc_inverse[2]=1;
      osc_inverse[3]=1;
      osc_scale_rate[4]=osc_scale_rate[2];
      break;

    case 3:
      osc_inverse[0]=2;
      osc_inverse[1]=2;
      osc_inverse[2]=2;
      osc_inverse[3]=1;
      osc_scale_rate[4]=osc_scale_rate[3];
      break;

    case 4:
      osc_inverse[0]=2;
      osc_inverse[1]=2;
      osc_inverse[2]=2;
      osc_inverse[3]=2;
      osc_scale_rate[4]=osc_scale_rate[0];
      break;

    case 5:
      osc_inverse[0]=4;
      osc_inverse[1]=2;
      osc_inverse[2]=2;
      osc_inverse[3]=2;
      osc_scale_rate[4]=osc_scale_rate[1];
      break;

    case 6:
      osc_inverse[0]=4;
      osc_inverse[1]=4;
      osc_inverse[2]=2;
      osc_inverse[3]=2;
      osc_scale_rate[4]=osc_scale_rate[2];
      break;

    case 7:
      osc_inverse[0]=4;
      osc_inverse[1]=4;
      osc_inverse[2]=4;
      osc_inverse[3]=2;
      osc_scale_rate[4]=osc_scale_rate[3];
      break; 
  }
  }

 //----------------------select chord table-----------------
switch(chord_mode){
  case 0:
  select_table=0;//4 chord
  break;

  case 1:
  select_table=1;//4 chord
  break;

  case 2:
  select_table=0;//3 chord
  break;

  case 3:
  select_table=1;//3 chord
  break;

  case 4:
  select_table=2;//3 chord
  break;

  case 5:
  select_table=2;//4 chord
  break;

}

  //----------------------mode select-----------------
if (digitalRead(0) == 1 && digitalRead(1) == 1) {
  select_mode = 1;//chord with bass
}
else if (digitalRead(0) == 0 && digitalRead(1) == 1) {
  select_mode = 2;//arpeggio
}
else if (digitalRead(0) == 1 && digitalRead(1) == 0) {
  select_mode = 0;//chord without bass
}


if(chord_mode==2 ||chord_mode==3 ||chord_mode==4){//set each oscillator frequency
  osc_scale_rate[0]=freq_rate[chord_3[select_chord3[select_table][thr%6]][0]]*osc_inverse[0];
  osc_scale_rate[1]=freq_rate[chord_3[select_chord3[select_table][thr%6]][1]]*osc_inverse[1];
  osc_scale_rate[2]=freq_rate[chord_3[select_chord3[select_table][thr%6]][2]]*osc_inverse[2];
};
if(chord_mode==0 ||chord_mode==1||chord_mode==5){
  osc_scale_rate[0]=freq_rate[chord_4[select_chord4[select_table][thr%6]][0]]*osc_inverse[0];
  osc_scale_rate[1]=freq_rate[chord_4[select_chord4[select_table][thr%6]][1]]*osc_inverse[1];
  osc_scale_rate[2]=freq_rate[chord_4[select_chord4[select_table][thr%6]][2]]*osc_inverse[2];
  osc_scale_rate[3]=freq_rate[chord_4[select_chord4[select_table][thr%6]][3]]*osc_inverse[3];
};

  //  -------------------push sw , change wavetable-------------------------------
  push_sw = digitalRead(6);
  if (push_sw == 0 && old_push_sw == 1) {//when push sw ON
    waveform++;//change waveform
    if (waveform > 7) {
      waveform = 0;
    }
      table_set();
  }
}

void qnt_set(){//quantize v/oct input
  if(chord_mode==0 ||chord_mode==1 ||chord_mode==2||chord_mode==3){//major scale
    for(j=0;j<31;j++){
      if(adc>=majthr[j] && adc<majthr[j+1]){
        thr=j;
      }
    }
    for(j=0;j<31;j++){
      qnt[j]=majqnt[j];
    }
  }

 if(chord_mode==4 ||chord_mode==5){//minor scale
   for(j=0;j<31;j++){
      if(adc>=minthr[j] && adc<minthr[j+1]){
        thr=j;
      }
    }
    for(j=0;j<31;j++){
      qnt[j]=minqnt[j];
    }
  }
}

void table_set() {//make wavetable
  switch  (waveform) {
    case 0:
        for (int i = 0; i < 256; i++) {  //saw
          wavetable[i] = i * 4 - 512;
        }
        break;

    case 1:
        for (int i = 0; i < 256; i++) {  //sin
          wavetable[i] = (sin(2 * M_PI * i  / 256)) * 511;
        }
        break;

    case 2:
        for (int i = 0; i < 128; i++) {  //squ
          wavetable[i] = 511;
          wavetable[i + 128] = -511;
        }
        break;

    case 3:
        for (int i = 0; i < 128; i++) {  //tri
          wavetable[i] = i * 8 - 511;
          wavetable[i + 128] = 511 - i * 8;
        }
        break;

    case 4:
        for (int i = 0; i < 128; i++) {  //oct saw
          wavetable[i] = i * 4 - 512 + i * 2;
          wavetable[i + 128] = i * 2 - 256 + i * 4;
        }
        break;

    case 5:
        for (int i = 0; i < 256; i++) {  //FM1
          wavetable[i] = (sin(2 * M_PI * i  / 256 + sin(2 * M_PI * 3 * i  / 256)) ) * 511;
        }
        break;

    case 6:
        for (int i = 0; i < 256; i++) {  //FM2
          wavetable[i] = (sin(2 * M_PI * i  / 256 + sin(2 * M_PI * 7 * i  / 256))) * 511;
        }
        break;

    case 7:
        for (int i = 0; i < 256; i++) {  //FM3
          wavetable[i] = (sin(2 * M_PI * i  / 256 + sin(2 * M_PI * 4 * i  / 256 + sin(2 * M_PI * 11 * i  / 256)))) * 511;
        }
        break;
  }
}

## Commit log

2023-01-20 first commit (schem finished)
    [PDSE1-S-M_CUI.step, PJ301M-12 Thonkiconn v0.2.stp, RK09K1130AH1.STEP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]
2023-01-21 finished schem and started pcb
    [RP2040-VCO.kicad_pcb, RP2040-VCO.kicad_sch]
2023-01-31 update schem + begin routing
    [AP2210K-5.0TRG1.stp, PDSE1-S-M_CUI.step, RP2040-VCO.kicad_pcb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]
2023-01-31 Routing finished
    [RP2040-VCO.kicad_pcb, RP2040-VCO.kicad_sch]
2023-02-18 update VCO pcb
    [RP2040-VCO.kicad_pcb, RP2040-VCO.kicad_sch]
2023-02-18 Add workflow
    [AP2210K-5.0TRG1.stp, RP2040-VCO.kicad_pcb, Seeed Studio XIAO RP2040 v26.step]
2023-02-18 add circuit gerber
    [RP2040-VCO--NPTH_map.gbr, RP2040-VCO--PTH_map.gbr, RP2040-VCO-B_Cu.gbl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]
2023-02-18 add jack BoM
2023-02-18 add main BoM and images
    [RP2040-VCO-bom.xlsx]
2023-02-18 add circuit BoM
2023-02-18 add front gerber
    [RP2040-VCO--NPTH_map.gbr, RP2040-VCO--PTH_map.gbr, RP2040-VCO-B_Cu.gbl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]
2023-02-18 add jack gerber
    [RP2040-VCO--NPTH_map.gbr, RP2040-VCO--PTH_map.gbr, RP2040-VCO-B_Cu.gbl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]
2023-04-06 update to v1.1
    [RP2040-VCO.kicad_pcb, RP2040-VCO.kicad_sch]
2023-04-09 update silkscreen
    [RP2040-VCO.kicad_pcb]
2023-04-09 update board with pullup on switch
    [RP2040-VCO.kicad_pcb, RP2040-VCO.kicad_sch]
2023-06-10 update label for tune (fix issue)
    [RP2040-VCO.kicad_pcb]
2023-10-11 add debounce for push button
2023-10-11 update pcb to v1.2 to fix switch issue with switch LED
    [RP2040-VCO.kicad_pcb, RP2040-VCO.kicad_sch]
2023-10-11 update fab files and repo organization
    [AP2210K-5.0TRG1.stp, PJ301M-12 Thonkiconn v0.2.stp, RK09K1130AH1.STEP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]
2023-10-11 update soldering instructions
2023-10-11 fix led button footprint
    [RP2040-VCO--NPTH_map.gbr, RP2040-VCO--PTH_map.gbr, RP2040-VCO-B_Cu.gbl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]
2024-06-12 roll back software following issue with debounce
    [Rp2040.ino]
2025-04-15 V1.4 update
    add extra 10k resistor on inv CV input (missing)
    Update BoM for clarity
    [RP2040-VCO.kicad_pcb, RP2040-VCO.kicad_sch, RP2040-VCO_V1.2--BoM.xlsx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]
2025-04-15 New gerbers for v1.4
    forgotten in previous commit
    [RP2040-VCO--NPTH_map.gbr, RP2040-VCO--PTH_map.gbr, RP2040-VCO-B_Cu.gbl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]
